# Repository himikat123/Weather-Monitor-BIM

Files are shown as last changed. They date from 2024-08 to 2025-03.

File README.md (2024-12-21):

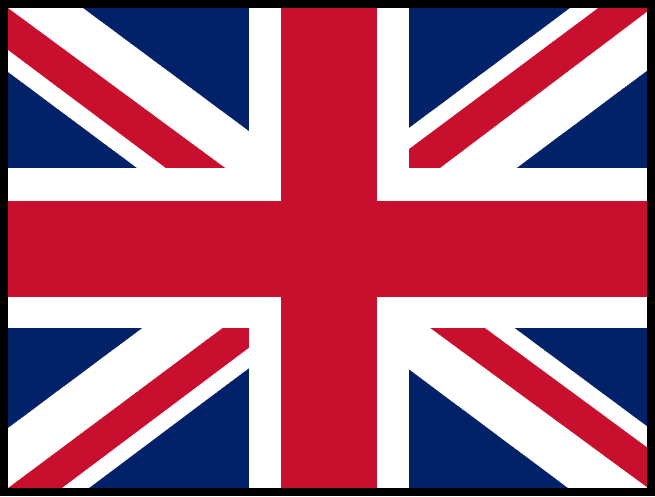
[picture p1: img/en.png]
Read this in english

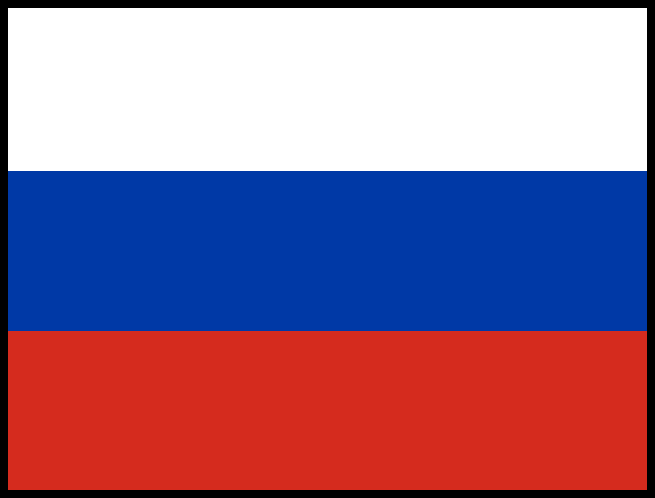
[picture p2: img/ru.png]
Читать на русском


# BIM weather monitor
## Weather monitor on ESP8266

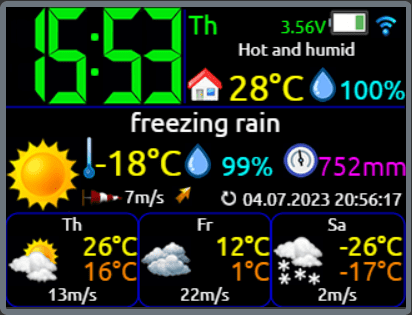
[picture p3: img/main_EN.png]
Weather monitor based on ESP8266


### Brief list of weather monitor features:

* Connect to home WiFi network 2.4 GHz
* Display current weather and weather forecast for 2 days
* Display temperature and humidity in the house
* Clock with NTP synchronization
* Sending and/or receiving data from/to thingspeak
* Sending data to narodmon
* Wireless temperature/pressure/humidity/ambient light sensors
* Support wired temperature/pressure/humidity/ambient light sensors
* Auto-adjust the brightness of the screen backlight (by ambient light sensor, by time or by the fact of sunrise and sunset)
* ILI9341 color display
* Support 2 languages: English, Russian
* Very flexible settings via web interface

## Wiring diagram for base weather monitor modules
To start and operate the weather monitor, just connect **display** to **ESP8266**. Connecting all other modules is optional.

Instead of diagrams I post half-drawings/half-photos, so that it is clear to beginners and even non-professionals. I ask professionals not to be upset, normal schematic diagramm will also be.

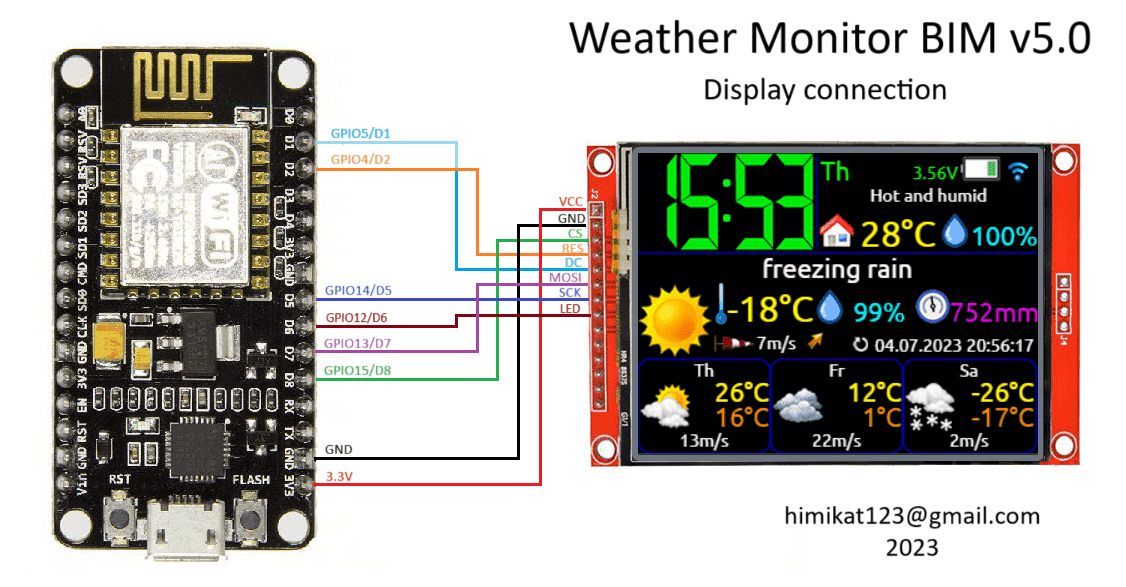
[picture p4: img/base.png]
weather monitor BIM base wiring diagramm


## Scheme of connecting wired sensors to the weather monitor
To the **weather monitor** can be connected to wired sensors for temperature, humidity, pressure and ambient light. **The monitor** supports the following sensors:
* BME280
* BMP180
* SHT21
* DHT22
* DS18B20
* MAX44009
* BH1750
* photoresistor

You can connect any one, several, or all sensors from this list at once. The connection diagram is as follows.

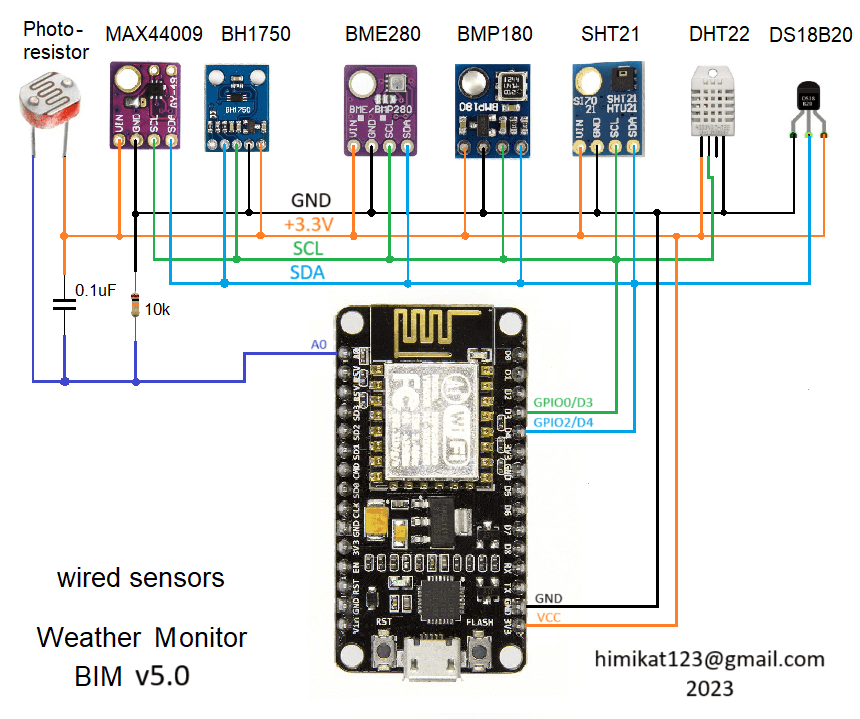
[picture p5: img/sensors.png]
weather monitor BIM wired sensors


## Weather monitor schematic diagramm

Well, as promised, a normal schematic diagramm for general development. 

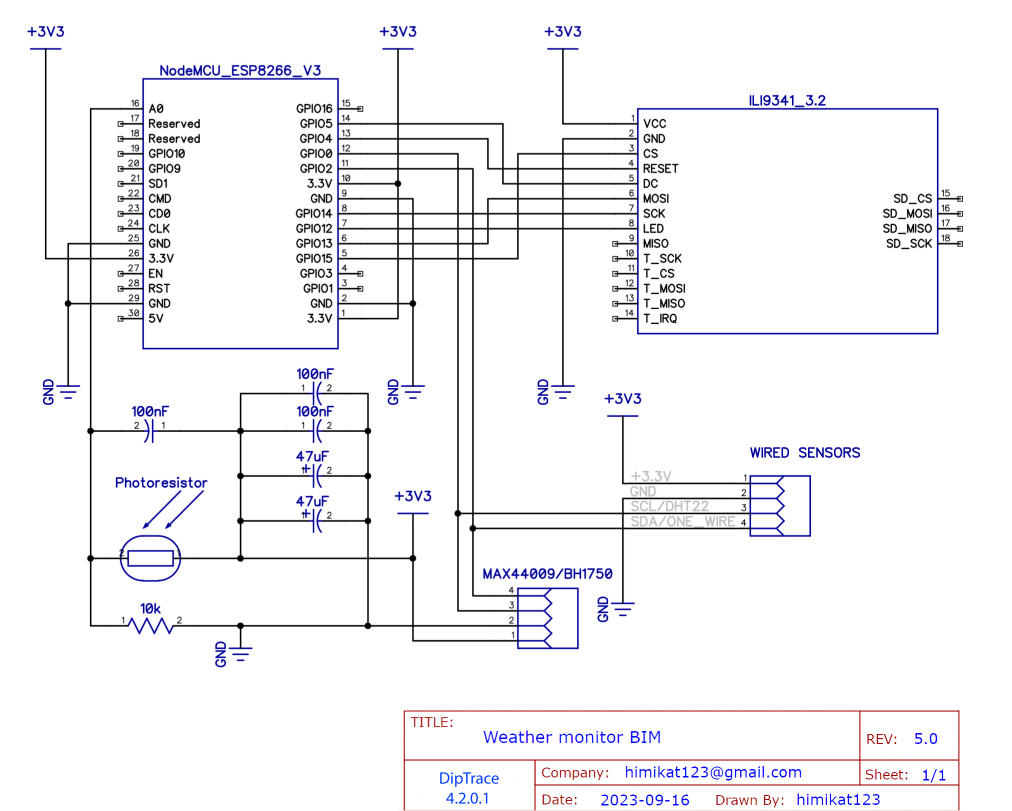
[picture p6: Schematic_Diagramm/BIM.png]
weather monitor BIM schematic diagramm


## Weather monitor firmware

To flash **ESP8266** with binary:
1. Download flash_download_tools from Espressif
2. Check the boxes as in the screenshot
3. Select the firmware binary and COM port number
4. Click the Start button

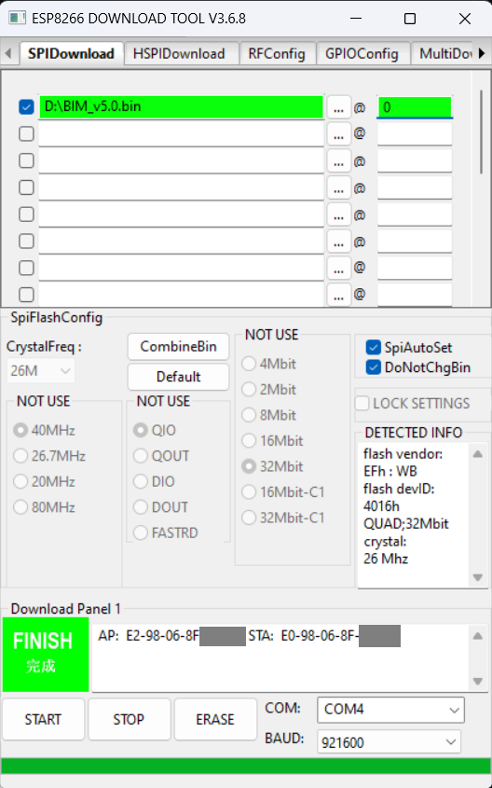
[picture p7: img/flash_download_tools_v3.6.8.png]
weather monitor BIM flashing


Or to compile and flash via Arduino **ESP8266**: 
1. Add **ESP8266** support to **Arduino IDE**, find [instruction](https://www.google.com/search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)
2. Add to **Arduino** plug-in for upload **LittleFS** find [instruction](https://www.google.com/search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)
3. Unpack the libraries from the file **libraries.zip** to the folder C:/Users/**Username**/Documents/Arduino/libraries
4. Flash the board with the sketch
5. Flash the files of the **LittleFS** file system: in Arduino you need to select **Tools --> ESP8266 LittleFS Data Upload**

After the flashing **the weather monitor** needs to be configured. An unconfigured device turns on the access point mode (creates a WiFi network) **Weather monitor BIM** with the default network password **1234567890**. And in the future to turn it on again you need to press and hold the **Settings** button until the access point symbol appears on the screen instead of the antenna symbol. After connecting a laptop or a smartphone to the **Weather monitor BIM** network, open a browser and navigate to **http://192.168.4.1**. If needed enter login **admin** and password **1111** to open the settings page. In the future, for security reasons, it is recommended to change the default password.

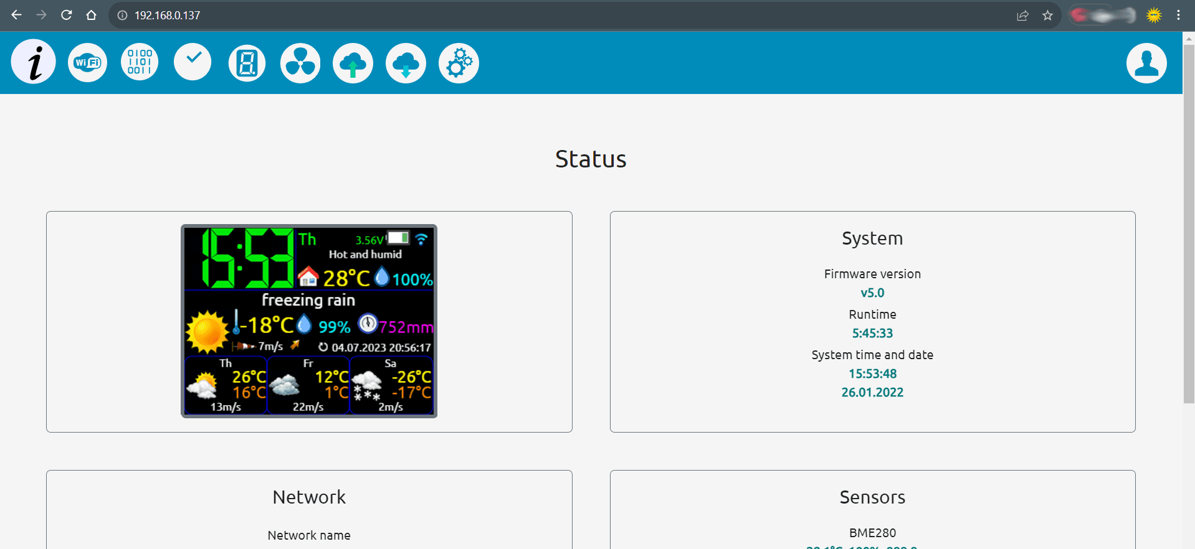
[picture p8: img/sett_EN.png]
weather monitor BIM login


Also when the device is already configured and connected to the network you can get into the settings without pressing the **Settings** button just enter the IP address of the **weather monitor** in the browser.

<hr>

And finally a few photos of the resulting device

<p align="center">
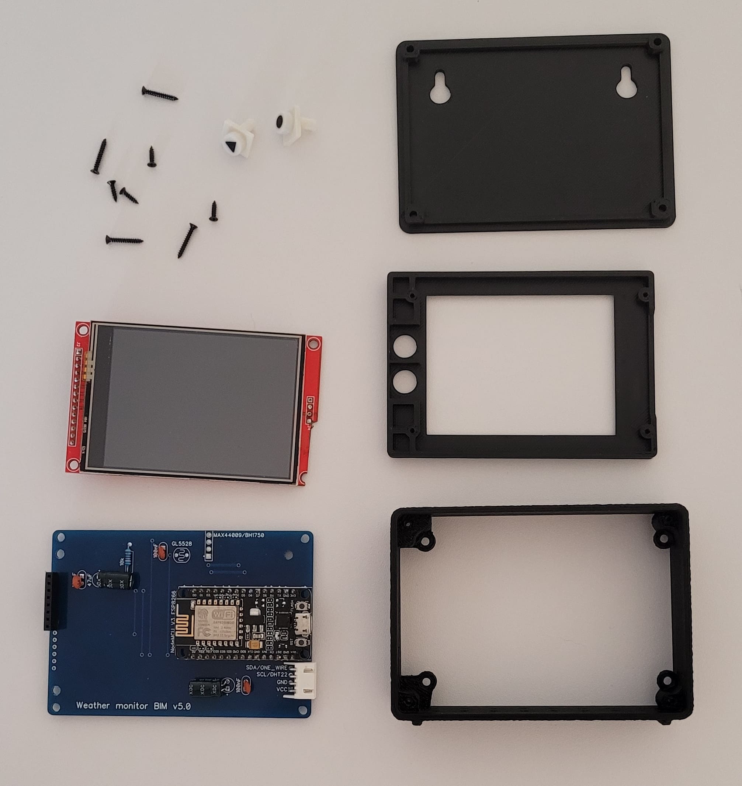
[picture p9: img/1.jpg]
    
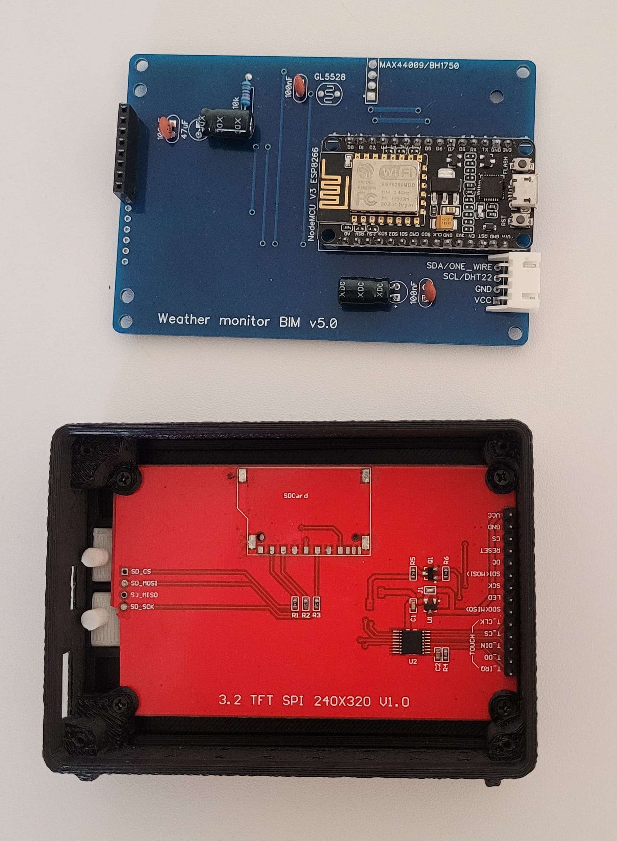
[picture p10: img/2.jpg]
    
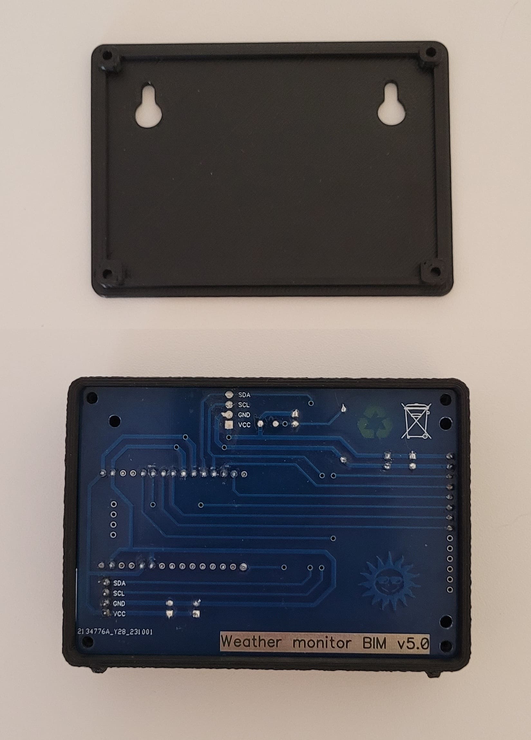
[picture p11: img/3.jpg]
    
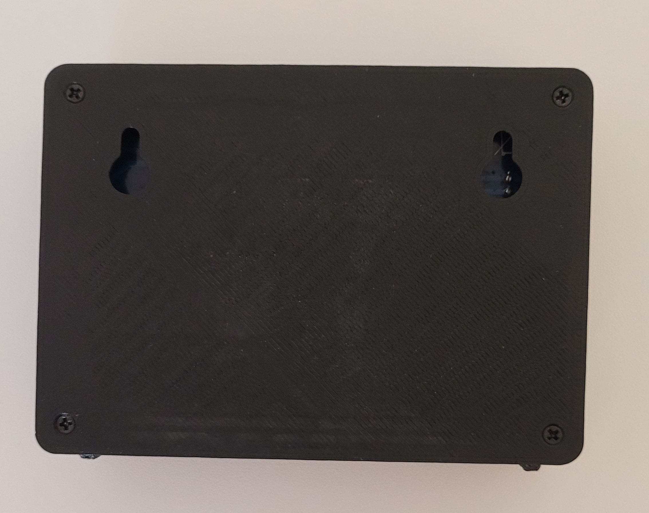
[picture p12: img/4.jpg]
    
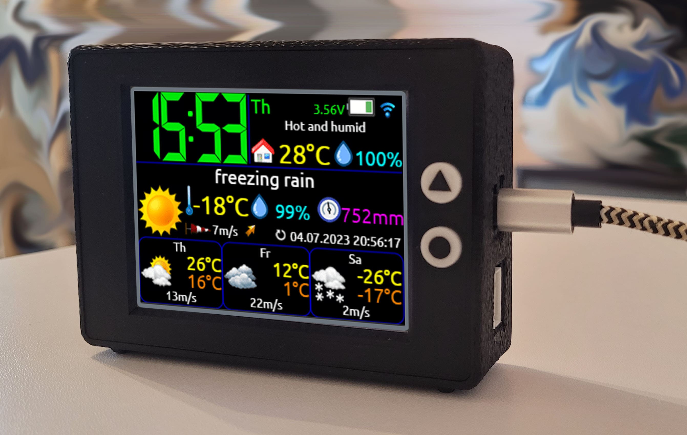
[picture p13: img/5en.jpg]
    
</p>

## Do you like the project? Buy me a coffee or a beer.

<a href="https://www.buymeacoffee.com/himikat123Q">
    Donate
</a>

<a href="https://www.paypal.com/donate/?hosted_button_id=R4QDCRKTC9QA6">
    
</a>

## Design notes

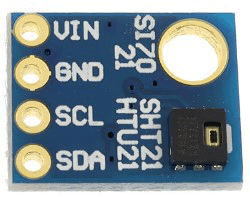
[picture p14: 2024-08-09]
img/sht21.png

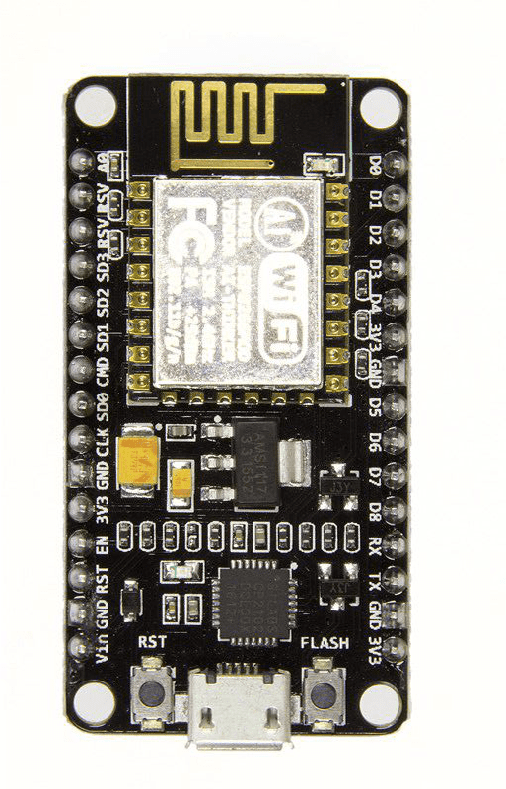
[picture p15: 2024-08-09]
img/esp8266.png

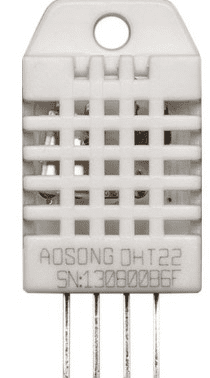
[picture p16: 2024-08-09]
img/dht22.png

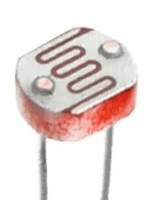
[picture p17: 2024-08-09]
img/photoresistor.png

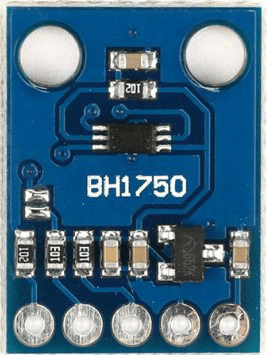
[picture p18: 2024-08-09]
img/bh1750.png

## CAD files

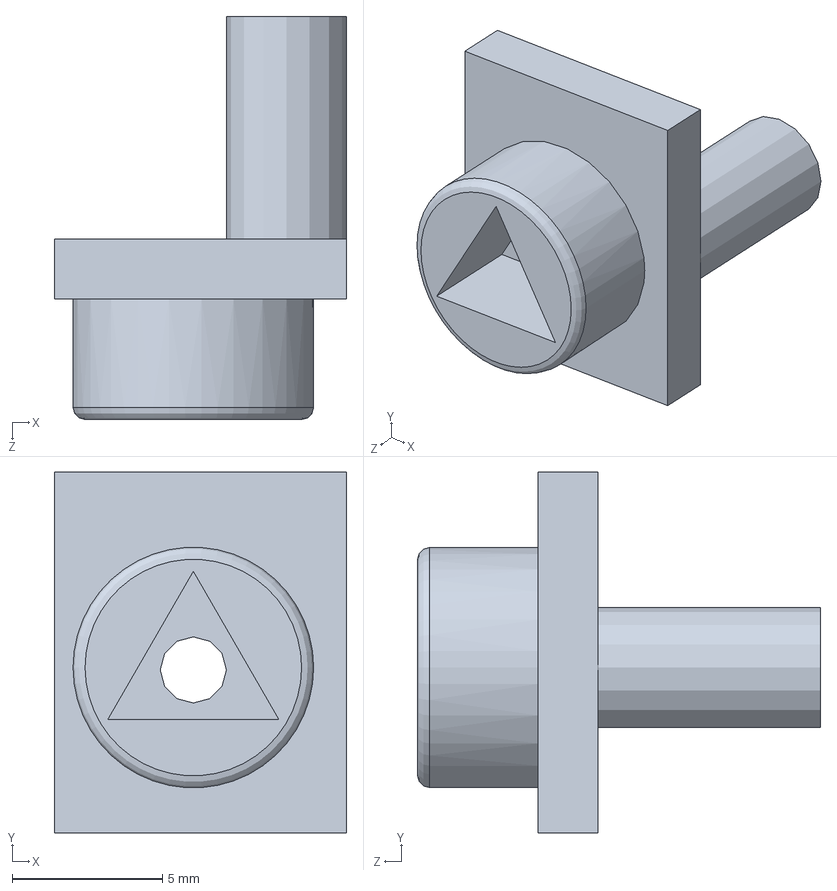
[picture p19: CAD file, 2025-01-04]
Enclosure/solidworks2023/buttons/settings_white.SLDPRT
9.72 x 12.0 x 13.4 mm

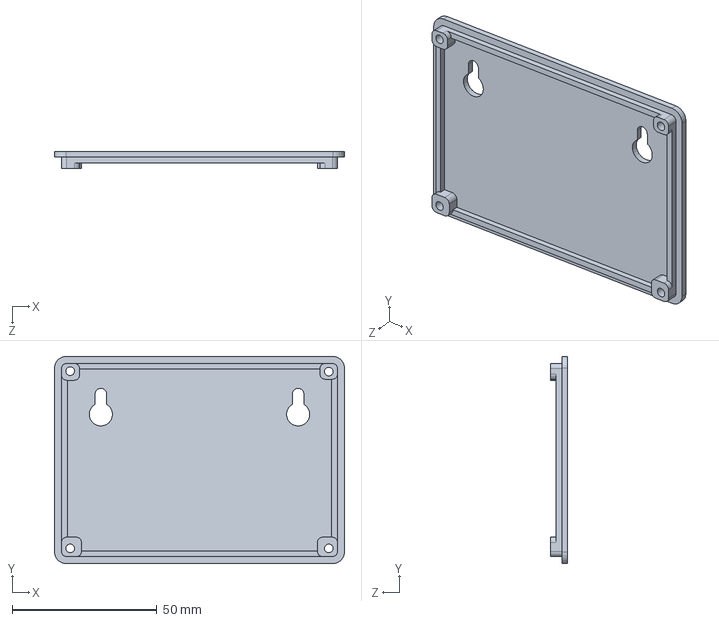
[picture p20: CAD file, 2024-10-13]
Enclosure/solidworks2023/cover/cover.SLDPRT
100.1 x 71.5 x 5.90 mm

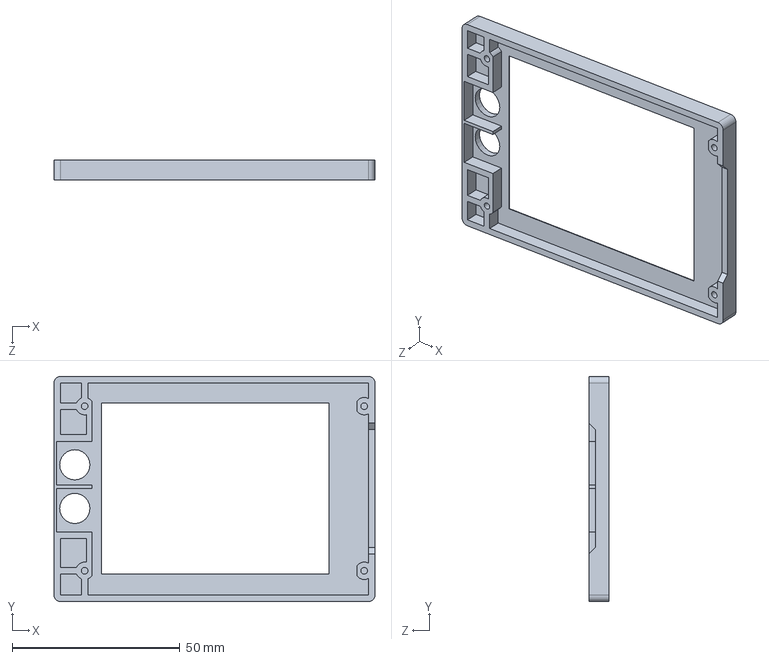
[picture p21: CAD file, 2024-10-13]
Enclosure/solidworks2023/face/face.SLDPRT
95.7 x 67.1 x 6.00 mm

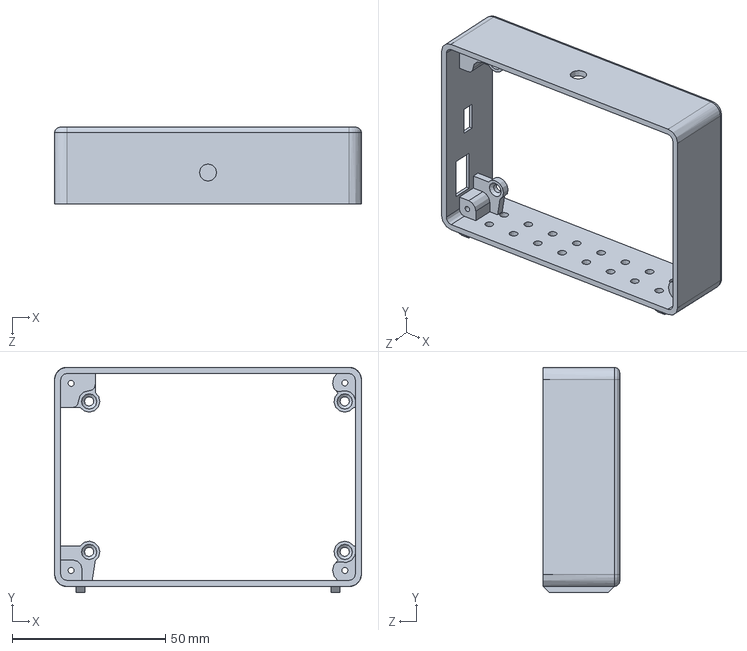
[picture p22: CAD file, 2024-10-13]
Enclosure/solidworks2023/frame/frame.SLDPRT
100.1 x 73.5 x 25.0 mm

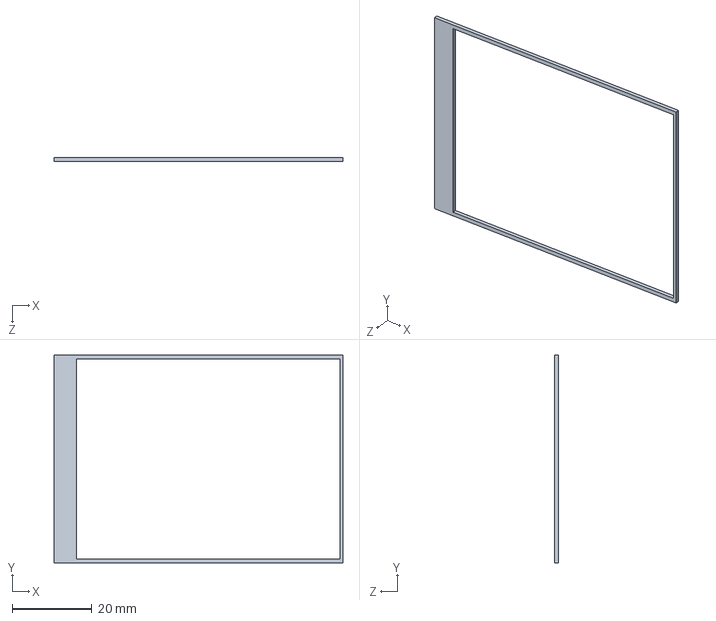
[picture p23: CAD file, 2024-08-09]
Enclosure/solidworks2023/pcb/disp_frame.SLDPRT
72.4 x 52.0 x 1.00 mm

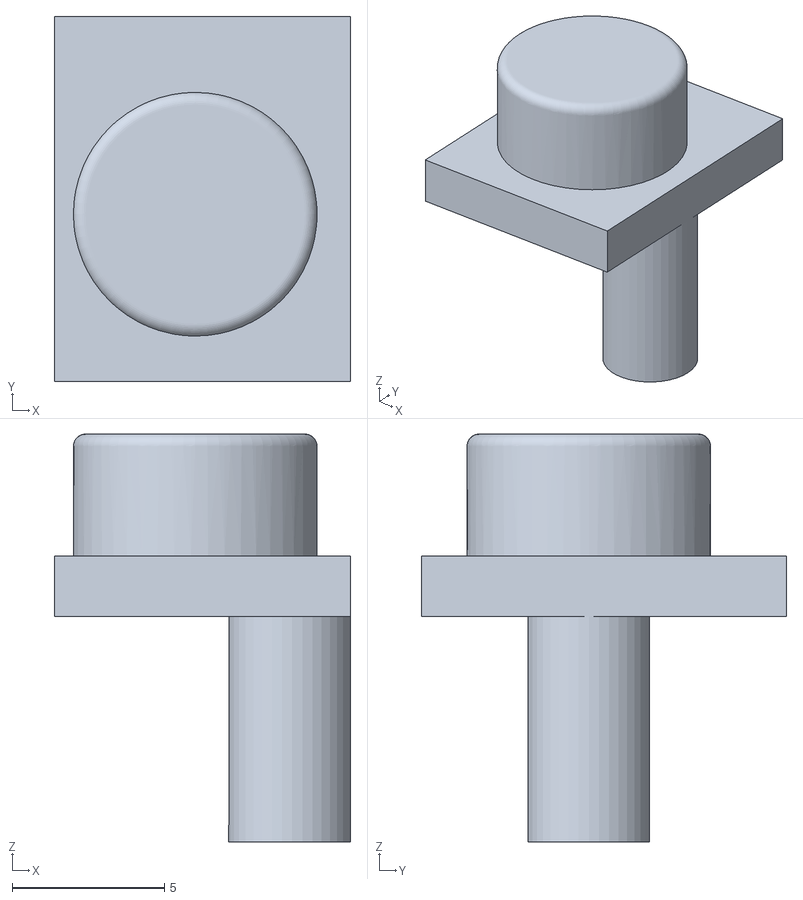
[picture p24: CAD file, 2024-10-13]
Enclosure/STL/buttons/one_color/settings.STL
9.72 x 12.0 x 13.4

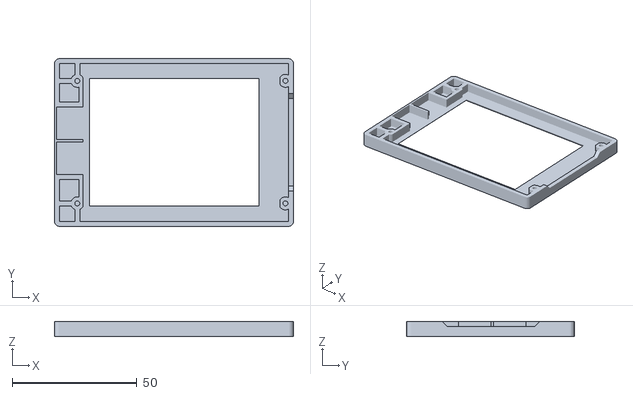
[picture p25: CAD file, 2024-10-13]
Enclosure/STL/face/face_wo_button_holes.STL
95.7 x 67.1 x 6.00

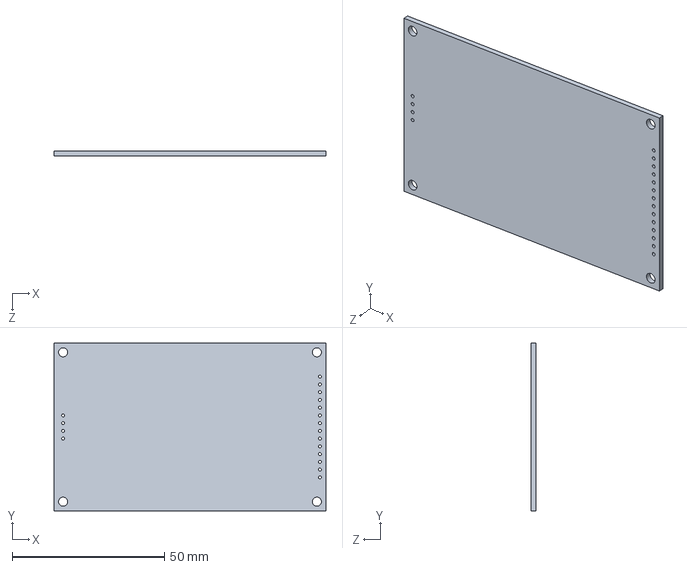
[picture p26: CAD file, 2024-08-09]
Enclosure/solidworks2023/pcb/display_board.SLDPRT
89.3 x 55.0 x 1.60 mm

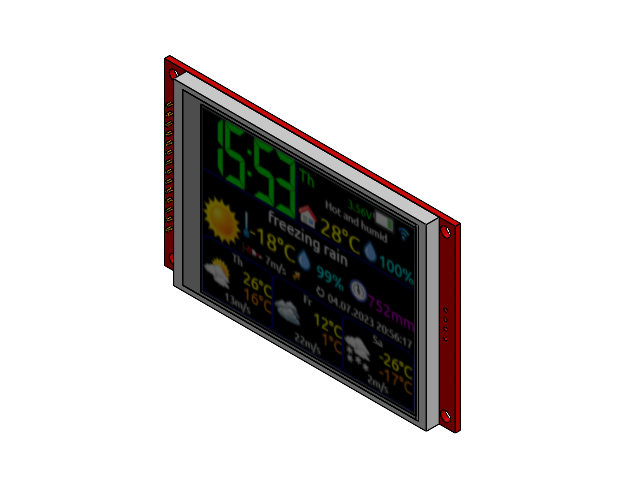
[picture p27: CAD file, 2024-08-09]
Enclosure/solidworks2023/pcb/display.SLDASM
screen
disp_frame
touch
display_board
14-Pin Header - Male - 2.54mm_1.step

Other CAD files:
Enclosure/solidworks2023/pcb/14-Pin Header - Male - 2.54mm.SLDASM
Enclosure/STL/buttons/two_colors/reset_white.STL
Enclosure/STL/cover/cover.STL
Enclosure/STL/frame/frame.STL
Enclosure/solidworks2023/buttons/reset_white.SLDPRT
Enclosure/STL/buttons/one_color/reset.STL
Enclosure/STL/buttons/two_colors/settings_white.STL
Enclosure/STL/face/face.STL
Enclosure/STL/frame/frame_wo_light_sensor_hole.STL
Enclosure/STL/buttons/two_colors/reset_black.STL
Enclosure/STL/buttons/two_colors/settings_black.STL
Enclosure/STL/frame/frame_wo_extra_holes.STL
Enclosure/STL/frame/frame_wo_sensors_connector_hole.STL
Enclosure/solidworks2023/buttons/reset_black.SLDPRT
Enclosure/solidworks2023/buttons/settings_black.SLDPRT
Enclosure/solidworks2023/pcb/board.SLDPRT
Enclosure/solidworks2023/pcb/screen.SLDPRT
Enclosure/solidworks2023/pcb/touch.SLDPRT
Enclosure/solidworks2023/screw1.SLDPRT
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

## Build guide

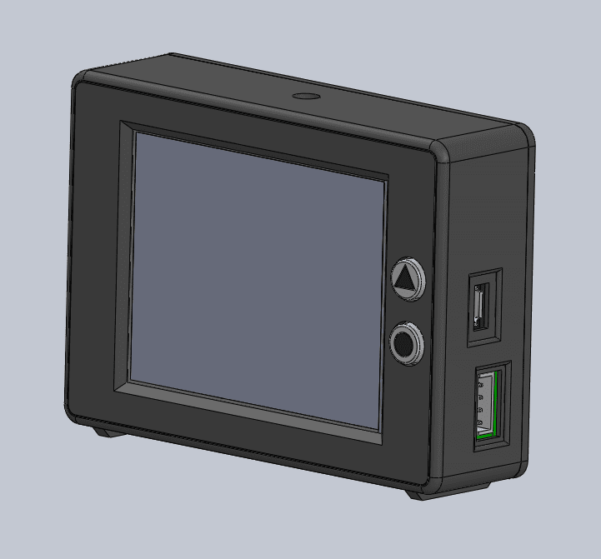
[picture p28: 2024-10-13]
Enclosure/solidworks2023/assembly.png

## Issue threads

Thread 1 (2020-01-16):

Node mcu 12e with 2.4 TFT touch

wisesokol, 2020-01-16:
День добрый.
Планирую использовать NOde mcu. датчиков не будет. Погода только с интернета.
На что следует обратить внимание для данной компановки в прошивке? К сожалению не особо силен в коде.

himikat123, 2020-03-30:
Здравствуйте. Если в коде не сильны прошивайте скомпиллированный bin файл. Без датчиков будет все работать. Все настройки делаются через Веб-интерфейс, в прошивке править ничего не нужно.

Closed 2020-03-30.

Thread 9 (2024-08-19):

Sensor errors

micko-24, 2024-08-19:
Sensors dht22 reads temperature and humidity and only shows temperature on the screen. BME280 mostly does not work, sometimes only shows humidity 100% and pressure 1350mm. ds18b20 reads temperature but does not show it on the screen.

himikat123, 2024-08-31:
Thanks, already fixed

Closed 2024-08-31.

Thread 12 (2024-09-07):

Error boxes

micko-24, 2024-09-07:
Dear Sir,
I had a box made according to your designs and the manufacturer informed me of these errors.

cover.stl
1 | Multi-shells detected
2 | Possible noise shells detected
3 | < 0.8mm wall thickness detected

reset_btn.stl
1 | Multi-shells detected
2 | < 0.8mm wall thickness detected

settings_btn.stl
1 | Multi-shells detected
2 | Possible noise shells detected
3 | < 0.8mm wall thickness detected

Can it be corrected?
Thanks.

himikat123, 2024-10-13:
Hi micko-24, thanks for reporting.  I have corrected and updated all 3D print files

micko-24, 2024-10-13:
Thank you, I just got a 3d printer, so I will print the new versions of the housing .

Closed 2024-10-19.

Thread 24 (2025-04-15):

Странное поведение экрана

240669, 2025-04-15:
Здравствуйте
Спаял плату, прошил контроллер, но изображение повернуто на 90 градусов.
Попробовал изменить в ардуино, но не смог скомпилировать, вылезает куча ошибок,
Помогите пожалуйста

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

240669, 2025-04-21:
Все нормально. Оказалось, что мой дисплей имеет драйвер ST7789. Небольшая правка кода решила все мои проблемы.

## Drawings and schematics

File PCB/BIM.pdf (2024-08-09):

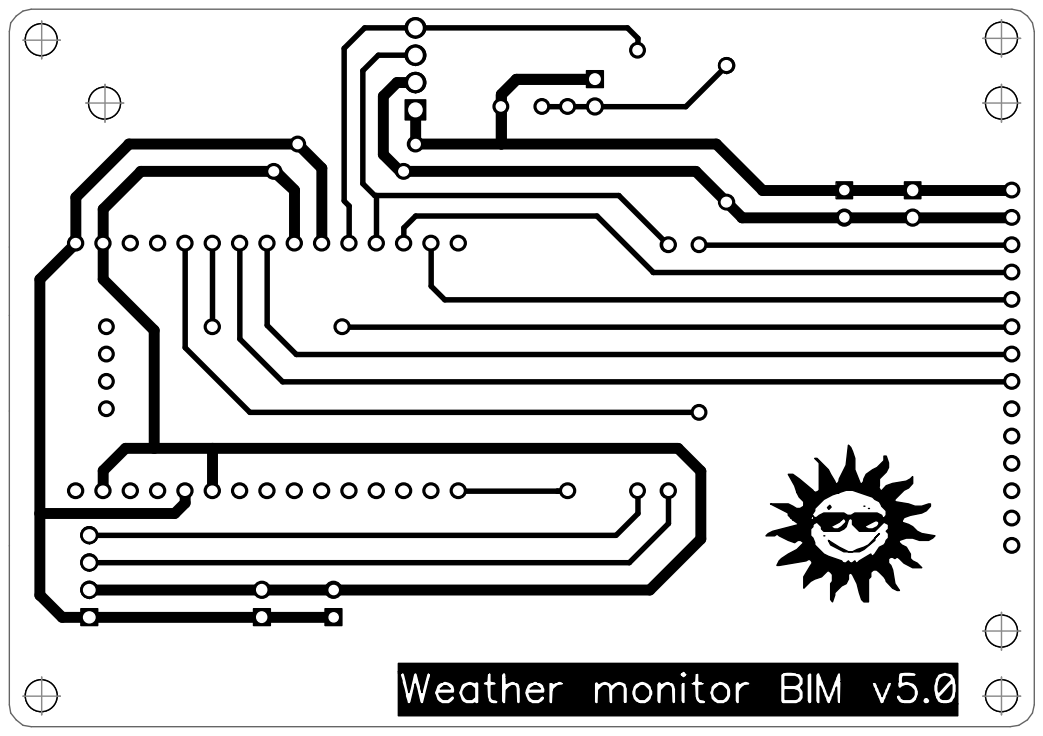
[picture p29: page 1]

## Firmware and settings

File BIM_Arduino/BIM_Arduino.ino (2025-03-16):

/**
 *  Weather Monitor BIM v5.8
 *  https://github.com/himikat123/Weather-Monitor-BIM
 *
 *  © himikat123@gmail.com, Nürnberg, Deutschland, 2016-2025
 *
 *  Generic ESP8266 Module
 *  Flash Size: "4MB (FS:2MB OTA:~1019KB)"
 *
 *  Arduino IDE v1.8.19
 *  ESP8266 board v3.1.2
 */

/* Arduino libraries */
#include <ESP8266WiFi.h>
#include <WiFiClient.h>
WiFiClient wifiClient;
#include <ESP8266WebServer.h>
ESP8266WebServer webServer(80);
File fsUploadFile;
#include <Arduino.h>
#include <ESP8266HTTPClient.h>
#include <Ticker.h>
#include <FS.h>
#include <LittleFS.h>
#include <time.h>
#include <Ticker.h>

Ticker clockPoints;

/* External Libraries */
#include <ArduinoJson.h> // v6.19.3 https://github.com/bblanchon/ArduinoJson
#include <TimeLib.h> // v1.6.0 https://playground.arduino.cc/Code/Time/
#include <ESP8266TrueRandom.h>

/* Own classes */
#include "globals.hpp"
Config config;
#include "sensors.hpp"
Sensors sensors;
#include "languages.hpp"
Lang lang;
#include "weather.hpp"
Weather weather;
#include "timentp.hpp"
TimeNTP timentp;
#include "thingspeak.hpp"
Thingspeak thingspeak;
#include "narodmon.hpp"
Narodmon narodmon;
#include "display.hpp"
Display display;
#include "network.hpp"
Network network;


void setup() {
  Serial.begin(74880);
  Serial.println("");
  Serial.println(SEPARATOR);
  Serial.println(SEPARATOR);
  Serial.println("*   Weather Monitor BIM " + String(global.fw) + "   © himikat123@gmail.com   2016-2025    *");
  Serial.println(SEPARATOR);
  Serial.println();

  pinMode(SETTINGS_BUTTON_PIN, INPUT);

  if(!LittleFS.begin()) {
    Serial.println("Flash FS initialisation failed!");
    while(1) yield();
  }

  config.readConfig();

  display.init();
  display.refresh(get_brightness());
  clockPoints.attach(0.5, clockPointsToggle);

  sensors.init();

  network.connect();
  
  webInterface_init();
}

void loop() {
  /**
   * Check if a button is pressed
   */
  // Enter access point mode if button is pressed
  if(digitalRead(SETTINGS_BUTTON_PIN) == 0) network.runAccessPoint();

  /**
   * Network connection if not connected
   */
  if(!network.isConnected()) {
    global.net_connected = false;
    if(!global.apMode) network.connect();
  }
  else global.net_connected = true;

  if(!global.apMode) {
    /**
     * Time synchronization with NTP server
     */
    if(config.clock_ntp_period()) {
      if((millis() - global.ntp_update) > config.clock_ntp_period() * 60000 or !global.clockSynchronized) {
        Serial.println(SEPARATOR);
        Serial.print("NTP synchronization... ");
        global.ntp_update = millis();
        if(network.isConnected()) timentp.get_time();
        else {
          global.ntp_update = 0;
          Serial.println("No internet connection");
        }
      }
    }

    /**
     * Receive data from thingspeak
     */
    if(config.thingspeakReceive_turnOn()) {
      if((millis() - global.thingspeakReceive) > (config.thingspeakReceive_period() * 60000) or global.thingspeakReceive == 0) {
        Serial.println(SEPARATOR);
        Serial.println("Receive data from thingspeak.com... ");
        global.thingspeakReceive = millis();
        if(network.isConnected()) thingspeak.receive();
        else {
          global.thingspeakReceive = 0;
          Serial.println("No internet connection");
        }
      }
    }

    /**
     * Send data to thingspeak
     */
    if(config.thingspeakSend_turnOn()) {
      if((millis() - global.thingspeakSend) > (config.thingspeakSend_period() * 60000) or global.thingspeakSend == 0) {
        Serial.println(SEPARATOR);
        Serial.println("Send data to thingspeak.com... ");
        global.thingspeakSend = millis();
        if(network.isConnected()) thingspeak.send();
        else {
          global.thingspeakSend = 0;
          Serial.println("No internet connection");
        }
      }
    }

    /**
     * Send data to narodmon
     */
    if(config.narodmonSend_turnOn()) {
      if((millis() - global.narodmonSend) > (config.narodmonSend_period() * 60000) or global.narodmonSend == 0) {
        Serial.println(SEPARATOR);
        Serial.println("Send data to narodmon... ");
        global.narodmonSend = millis();
        if(network.isConnected()) narodmon.send();
        else {
          global.narodmonSend = 0;
          Serial.println("No internet connection");
        }
      }
    }
    
    /**
     * Weather update 
     * every 20 minutes for open-meteo 
     * or every 60 minutes for weatherbit. 
     * If the last update was with an error, then after 5 minutes
     */
    uint32_t weatherUpd = config.weather_provider() == 0 ? 1200 : 3600;
    if(
      (now() - weather.get_currentUpdated() > weatherUpd && weather.get_errorUpdate() == 0) ||
      (weather.get_errorUpdate() && (now() - weather.get_errorUpdate() > 300))
    ) {
      Serial.println(SEPARATOR);
      Serial.println("Current weather update... ");
      weather.reset_errorUpdate();
      if(network.isConnected()) weather.update();
      else Serial.println("No internet connection");
    }
  }

  /**
   * Wired sensors update
   * every 5 seconds
   */
  if(millis() - global.sensors_update > 5000) {
    global.sensors_update = millis();
    sensors.read(); 
    
    comfortCalculate();
  }

  /**
   * List of available networks update
   * every 30 seconds
   */
  if(millis() - global.networks_update > 30000) {
    network.scan();
  }

  display.refresh(get_brightness());
  delay(10);

  webServer.handleClient();
}

void clockPointsToggle() {
  global.clockPoints = !global.clockPoints;
}

/**
 * Calculate comfort level 
 */
void comfortCalculate() {
  float temp = 40400.0;
  float hum = 40400.0;
  int tempLevel = 1;
  int humLevel = 1;
  bool heater = false;
  bool cooler = false;
  bool humidifier = false;
  bool dehumidifier = false;
  
  switch(config.comfort_temp_source()) {
    case 1: temp = weather.get_currentTemp(config.weather_temp_corr()); break;  // temperature from weather forecast
    case 2: {                                                                   // temperature from thingspeak
      if(now() - thingspeak.get_updated() < config.thingspeakReceive_expire() * 60)
        temp = thingspeak.get_field(config.comfort_temp_thing());
    }; break;
    case 3: temp = sensors.get_bme280_temp(config.bme280_temp_corr()); break;   // temperature from BME280
    case 4: temp = sensors.get_bmp180_temp(config.bmp180_temp_corr()); break;   // temperature from BMP180
    case 5: temp = sensors.get_sht21_temp(config.sht21_temp_corr()); break;     // temperature from SHT21
    case 6: temp = sensors.get_dht22_temp(config.dht22_temp_corr()); break;     // temperature from DHT22
    case 7: temp = sensors.get_ds18b20_temp(config.ds18b20_temp_corr()); break; // temperature from DS18B20
    default: ; break;
  }
  
  switch(config.comfort_hum_source()) {
    case 1: hum = weather.get_currentHum(config.weather_hum_corr()); break;     // humidity from weather forecast
    case 2: {                                                                   // humidity from thingspeak
      if(now() - thingspeak.get_updated() < config.thingspeakReceive_expire() * 60)
        hum = thingspeak.get_field(config.comfort_hum_thing());
    }; break;
    case 3: hum = sensors.get_bme280_hum(config.bme280_hum_corr()); break;      // humidity from BME280
    case 4: hum = sensors.get_sht21_hum(config.sht21_hum_corr()); break;        // humidity from SHT21
    case 5: hum = sensors.get_dht22_hum(config.dht22_hum_corr()); break;        // humidity from DHT22
    default: ; break;
  }

  if(sensors.checkTemp(temp)) {
    if(temp < config.comfort_temp_min()) heater = true;
    if(temp > config.comfort_temp_min()) heater = false;
    if(temp > config.comfort_temp_max()) cooler = true;
    if(temp < config.comfort_temp_max()) cooler = false;
    if(!heater and !cooler) tempLevel = 0;
    if(heater and !cooler) tempLevel = 2;
    if(!heater and cooler) tempLevel = 1;
  }
  else tempLevel = -1;

  if(sensors.checkHum(hum)) {
    if(hum < config.comfort_hum_min()) humidifier = true;
    if(hum > config.comfort_hum_min()) humidifier = false;
    if(hum > config.comfort_hum_max()) dehumidifier = true;
    if(hum < config.comfort_hum_max()) dehumidifier = false;
    if(!humidifier and !dehumidifier) humLevel = 0;
    if(humidifier and !dehumidifier) humLevel = 2;
    if(!humidifier and dehumidifier) humLevel = 1;
  }
  else humLevel = -1;

  global.comfort = 1;
  if(tempLevel == -1 && humLevel == -1) global.comfort = 0;
  if(tempLevel == 1 && humLevel < 1) global.comfort = 2;
  if(tempLevel == 2 && humLevel < 1) global.comfort = 3;
  if(tempLevel < 1 && humLevel == 1) global.comfort = 5;
  if(tempLevel < 1 && humLevel == 2) global.comfort = 4;
  if(tempLevel == 1 && humLevel == 1) global.comfort = 6;
  if(tempLevel == 1 && humLevel == 2) global.comfort = 7;
  if(tempLevel == 2 && humLevel == 1) global.comfort = 8;
  if(tempLevel == 2 && humLevel == 2) global.comfort = 9;
}

/**
 * Display brightness calculation
 */
unsigned int get_brightness() {
  #define HOUR 0
  #define MINUTE 1

  switch(config.display_brightMethod()) {

    /* By sunrise and sunset */
    case 0:
      return(weather.get_isDay() ? config.display_brightness_day() : config.display_brightness_night());

    /* By ambeint light sensor */
    case 1: {
      float bright = 0.0;
      if(config.display_lightSensor() == 0) {
        bright = sensors.checkVolt(sensors.get_analog_voltage(config.analog_voltage_corr())) ? sensors.get_analog_voltage(config.analog_voltage_corr()) * 30 : 50;
      }
      if(config.display_lightSensor() == 1) {
        bright = sensors.checkLight(sensors.get_max44009_light(config.max44009_light_corr())) ? sensors.get_max44009_light(config.max44009_light_corr()) : 50;
      }
      if(config.display_lightSensor() == 2) {
        bright = sensors.checkLight(sensors.get_bh1750_light(config.bh1750_light_corr())) ? sensors.get_bh1750_light(config.bh1750_light_corr()) : 50;
      }
      bright *= (float)config.display_lightSensor_sensitivity() / 20.0;
      if(bright < 1.0) bright = 1.0;
      if(bright > 100.0) bright = 100.0;
      return(round(bright));
    };

    /* By user defined time */
    case 2: {
      unsigned int morning = config.display_dayTime(HOUR) * 60 + config.display_dayTime(MINUTE);
      unsigned int evening = config.display_nightTime(HOUR) * 60 + config.display_nightTime(MINUTE);
      unsigned int cur_time = int(hour()) * 60 + minute();
      unsigned int bright = (cur_time >= morning and cur_time < evening) ? 
        config.display_brightness_day() : config.display_brightness_night();
      return(bright);
    };

    /* Constant brightness */
    case 3:
      return(config.display_brightness_day());

    default:
      return 50; break;
  }
}

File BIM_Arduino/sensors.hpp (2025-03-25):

#include <Wire.h>
#include <Adafruit_BME280.h> // v2.0.2 https://github.com/adafruit/Adafruit_BME280_Library
#include <Adafruit_BMP085.h> // v1.1.0 https://github.com/adafruit/Adafruit-BMP085-Library
#include "SHT21.h" // https://github.com/markbeee/SHT21
#include "DHTesp.h" // v1.17.0 http://desire.giesecke.tk/index.php/2018/01/30/esp32-dht11/
#include <MAX44009.h> // v1.2.3 https://github.com/dantudose/MAX44009
#include <BH1750.h> // v1.1.4 https://github.com/claws/BH1750
#include <OneWire.h> // v2.3.7 https://github.com/PaulStoffregen/OneWire
#include <DallasTemperature.h> // v3.9.1 https://github.com/milesburton/Arduino-Temperature-Control-Library

OneWire             oneWire(ONE_WIRE_BUS_PIN);
DallasTemperature   term(&oneWire);
DeviceAddress       thermometer;
SHT21               SHT21;
DHTesp              dht;
MAX44009            max_light;
BH1750              lightMeter(0x23);
Adafruit_BMP085     bmp;
Adafruit_BME280     bme;
Adafruit_Sensor     *bme_temp = bme.getTemperatureSensor();
Adafruit_Sensor     *bme_pressure = bme.getPressureSensor();
Adafruit_Sensor     *bme_humidity = bme.getHumiditySensor();

class Sensors {
  public:
    void init(void);
    void read(void);
    
    bool checkTemp(float temp);
    bool checkHum(float hum);
    bool checkPres(float pres);
    bool checkLight(float light);
    bool checkVolt(float volt);
    bool checkBatVolt(float volt);
    bool checkBatLvl(int lvl);
    bool checkBatPercent(int percent);
    
    float get_bme280_temp(float corr);
    float get_bme280_hum(float corr);
    float get_bme280_pres(float corr);
    float get_bmp180_temp(float corr);
    float get_bmp180_pres(float corr);
    float get_sht21_temp(float corr);
    float get_sht21_hum(float corr);
    float get_dht22_temp(float corr);
    float get_dht22_hum(float corr);
    float get_ds18b20_temp(float corr);
    float get_max44009_light(float corr);
    float get_bh1750_light(float corr);
    float get_analog_voltage(float corr);
    
  private:
    bool _bme280_det = false;
    bool _bmp180_det = false;
    bool _sht21_det = false;
    bool _dht22_det = false;
    bool _ds18b20_det = false;
    bool _max44009_det = false;
    bool _bh1750_det = false;
    
    float _bme280_temp = 40400.0;
    float _bme280_hum = 40400.0;
    float _bme280_pres = 40400.0;
    float _bmp180_temp = 40400.0;
    float _bmp180_pres = 40400.0;
    float _sht21_temp = 40400.0;
    float _sht21_hum = 40400.0;
    float _dht22_temp = 40400.0;
    float _dht22_hum = 40400.0;
    float _ds18b20_temp = 40400.0;
    float _max44009_light = -1000.0;
    float _bh1750_light = -10000.0;
    float _analog_voltage = -10000.0;

    void _BME280Init(void);
    void _BMP180Init(void);
    void _SHT21Init(void);
    void _DHT22Init(void);
    void _DS18B20Init(void);
    void _MAX44009Init(void);
    void _BH1750Init(void);
    
    void _BME280Read(void);
    void _BMP180Read(void);
    void _SHT21Read(void);
    void _DHT22Read(void);
    void _DS18B20Read(void);
    void _MAX44009Read(void);
    void _BH1750Read(void);
    void _AnalogRead(void);
};

/**
 * Initialize all sensors
 */
void Sensors::init(void) {
  Serial.println(SEPARATOR);
  Serial.println("Sensor initialization");
  
  Wire.begin(ONE_WIRE_BUS_PIN, DHT22_PIN);
  _BME280Init();
  _BMP180Init();
  _SHT21Init();
  _MAX44009Init();
  _BH1750Init();
  _DS18B20Init();
  _DHT22Init();
  
  Serial.printf("%s %s%s\r\n", "BME280:   ", _bme280_det ? "" : "NOT ", "Detected");
  Serial.printf("%s %s%s\r\n", "BMP180:   ", _bmp180_det ? "" : "NOT ", "Detected");
  Serial.printf("%s %s%s\r\n", "SHT21:    ", _sht21_det ? "" : "NOT ", "Detected");
  Serial.printf("%s %s%s\r\n", "DS18B20:  ", _ds18b20_det ? "" : "NOT ", "Detected");
  Serial.printf("%s %s%s\r\n", "DHT22:    ", _dht22_det ? "" : "NOT ", "Detected");
  Serial.printf("%s %s%s\r\n", "MAX44009: ", _max44009_det ? "" : "NOT ", "Detected");
  Serial.printf("%s %s%s\r\n", "BH1750:   ", _bh1750_det ? "" : "NOT ", "Detected");
  
  read();
}

/**
 * Reads all sensors
 */
void Sensors::read(void) {
  pinMode(DHT22_PIN, INPUT);
  digitalWrite(DHT22_PIN, LOW);
  _BME280Read();
  _BMP180Read();
  _SHT21Read();
  _MAX44009Read();
  _BH1750Read();
  _DS18B20Read();
  _DHT22Read();
  _AnalogRead();
}

/**
 * Check if temperature is within the normal range
 */
bool Sensors::checkTemp(float temp) {
  return (temp >= -55.0 and temp <= 100.0);
}

/**
 * Check if humidity is within the normal range
 */
bool Sensors::checkHum(float hum) {
  return (hum >= 0.0 and hum <= 100.0);
}

/**
 * Check if pressure is within the normal range
 */
bool Sensors::checkPres(float pres) {
  return (pres >= 400.0 and pres <= 1200.0);
}

/**
 * Check if ambient light is within the normal range
 */
bool Sensors::checkLight(float light) {
  return (light >= 0.0 and light <= 120000.0);
}

/**
 * Check if analog voltage is within the normal range
 */
bool Sensors::checkVolt(float volt) {
  return (volt >= 0.0 and volt <= 3.3);
}

/**
 * Check if battery voltage is within the normal range
 */
bool Sensors::checkBatVolt(float volt) {
  return (volt >= 0.0 and volt <= 12.0);
}

/**
 * Check if battery level is within the normal range
 */
bool Sensors::checkBatLvl(int lvl) {
  return (lvl >= 1 and lvl <= 4);
}

/**
 * Check if battery percentage is within the normal range
 */
bool Sensors::checkBatPercent(int percent) {
  return (percent >= 0 and percent <= 100);
}

/**
 * Getters
 */
float Sensors::get_bme280_temp(float corr) {
  return _bme280_temp + corr;
}

float Sensors::get_bme280_hum(float corr) {
  return _bme280_hum + corr;
}

float Sensors::get_bme280_pres(float corr) {
  return _bme280_pres + corr;
}

float Sensors::get_bmp180_temp(float corr) {
  return _bmp180_temp + corr;
}

float Sensors::get_bmp180_pres(float corr) {
  return _bmp180_pres + corr;
}

float Sensors::get_sht21_temp(float corr) {
  return _sht21_temp + corr;
}

float Sensors::get_sht21_hum(float corr) {
  return _sht21_hum + corr;
}

float Sensors::get_dht22_temp(float corr) {
  return _dht22_temp + corr;
}

float Sensors::get_dht22_hum(float corr) {
  return _dht22_hum + corr;
}

float Sensors::get_ds18b20_temp(float corr) {
  return _ds18b20_temp + corr;
}

float Sensors::get_max44009_light(float corr) {
  return _max44009_light + corr;
}

float Sensors::get_bh1750_light(float corr) {
  return _bh1750_light + corr;
}

float Sensors::get_analog_voltage(float corr) {
  return _analog_voltage + corr;
}

/**
 * Initialize BME280 sensor
 */
void Sensors::_BME280Init(void) {
  _bme280_det = bme.begin(0x76, &Wire);
  if(!_bme280_det) _bme280_det = bme.begin(0x77, &Wire);
}

/**
 * Initialize BMP180 sensor
 */
void Sensors::_BMP180Init(void) {
  if(bmp.begin()) _bmp180_det = true;
}
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

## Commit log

2018-09-04 Create pcb
2020-12-30 Rename outside sensor/main.ino to outside_sensor/outside_sensor.ino
2023-11-17 migrate from another repository
    [14-Pin Header - Male - 2.54mm.SLDASM, 1x9.STEP, ESP8266.stp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]
2024-01-03 folders rename
    [14-Pin Header - Male - 2.54mm.SLDASM, 1x9.STEP, ESP8266.stp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]
2024-08-09 stl export
    [cover.STL, face.STL, face_black.STL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]
2024-08-09 fine-tuning the display cutout
    [face.SLDPRT]
2024-08-09 photos of the device
2024-08-11 compatibility with old wireless sensor
2024-08-27 typo in wired sensor connector
2024-08-31 Fixed reading of wired sensors
    [BIM_Arduino.ino, globals.hpp, sensors.hpp]
2024-10-13 3d print files update
    [cover.SLDPRT, cover.STL, cover_black.STL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]
2024-12-08 fix of analog sensor labels
2024-12-08 fix for reading light sensor sensitivity settings
    [globals.hpp]
2024-12-22 switched to a new web interface
2025-01-03 correction of current weather data
    [globals.hpp, weather.hpp, web.ino]
2025-01-03 fix of comfort level calculation
    [BIM_Arduino.ino, globals.hpp]
2025-01-03 clarifying/correcting the comfort level
    [BIM_Arduino.ino]
2025-01-04 holes for disassembly
    [reset_white.SLDPRT, reset_white.STL, settings_white.SLDPRT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]
2025-01-06 improving the stability of web interface loading
    [BIM_Arduino.ino, globals.hpp]
2025-03-16 autostart access point if network connection failed
    [BIM_Arduino.ino, globals.hpp]
2025-03-25 expanded the pressure range
